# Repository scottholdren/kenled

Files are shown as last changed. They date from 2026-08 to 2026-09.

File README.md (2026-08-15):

# KenLED

An art installation: a wall of **89 glass bricks**, each lit by an addressable
RGB LED, playing pixel animations designed in a browser and delivered to the
wall over the air.

Design an animation on the web, hit **Publish**, and within seconds every
device subscribed to the wall — the installation itself and a pocket-sized
monitor — is playing it.

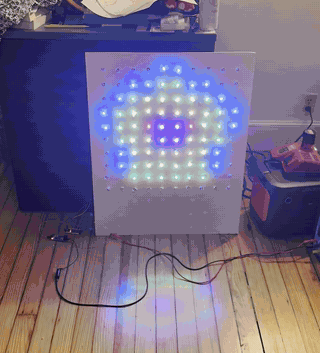
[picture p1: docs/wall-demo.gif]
The test rig playing the self-playing snake


*The 10×10 test rig: 100 WS2811 bullet pixels in foam board, driven by the
production firmware, playing a generated self-playing snake game published
over Wi-Fi seconds earlier. The glass-brick wall replaces the foam board;
everything else ships as-is.*

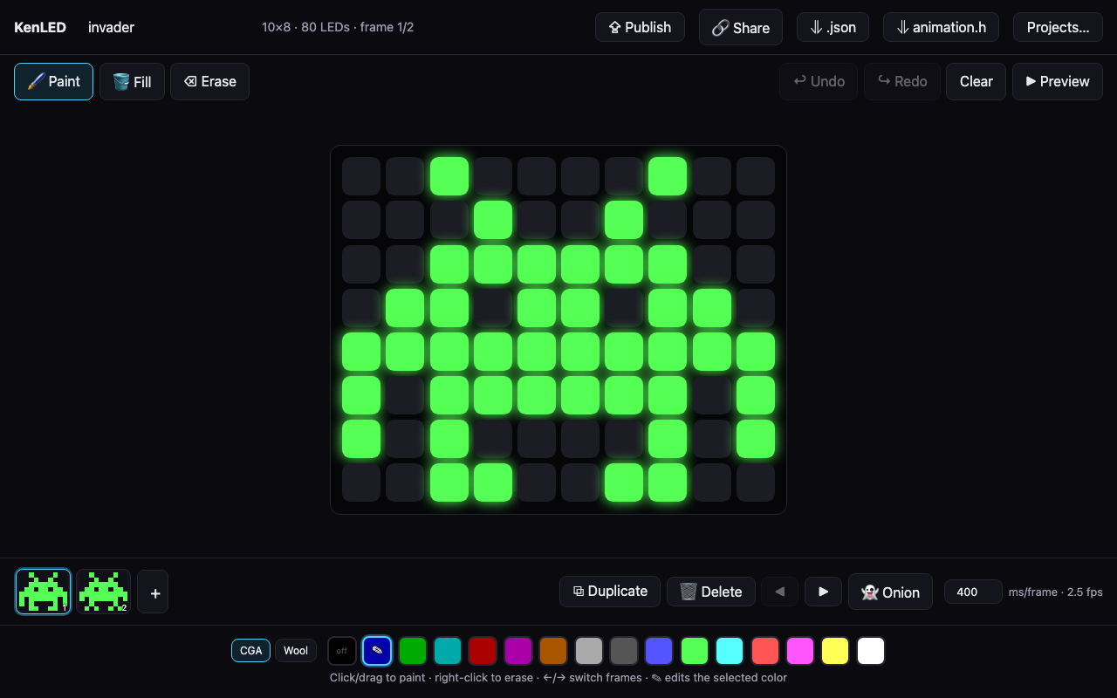
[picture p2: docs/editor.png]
The KenLED designer


## How it works

```
Designer's browser                 GitHub                       The wall
┌──────────────────┐  commit   ┌───────────────┐  poll ~60s  ┌──────────────────┐
│  KenLED designer │──────────▶│ wall branch:  │◀────────────│ ESP32-S3 +       │
│  (GitHub Pages)  │  via API  │ current.json  │             │ 89 WS2811 pixels │
│  [⇪ Publish]     │           └───────────────┘◀──────┐     └──────────────────┘
└──────────────────┘                                   │     ┌──────────────────┐
                                                       └─────│ LilyGo T-Dongle  │
                                                             │ (pocket mirror)  │
                                                             └──────────────────┘
```

- **The designer** is a static React app on GitHub Pages. Publishing commits
  the animation as `current.json` to this repo's `wall` branch through the
  GitHub API (a fine-grained token, held only in the designer's browser).
- **Devices** poll the branch-ref API (uncached; conditional 304s are free)
  and fetch content by immutable commit sha — updates land on the next poll,
  never stale-cached.
- **Playback never depends on the network.** Devices boot from a flash cache,
  fall back to a compiled-in animation, and just keep playing if Wi-Fi dies.
  Every published animation is also permanently recoverable from git history.

## The designer

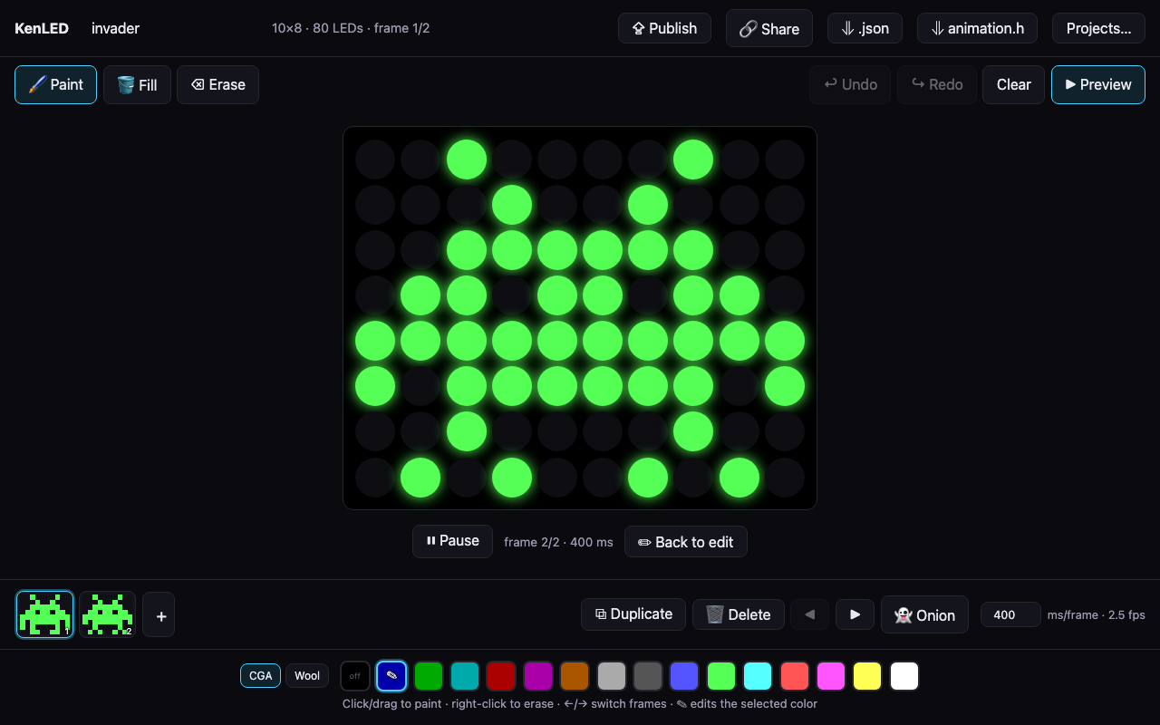
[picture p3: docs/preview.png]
Preview mode


- Configurable grid (default 10×8 — the brick wall), 16-color palette with
  **CGA** and **Minecraft wool** presets, every swatch editable
- Paint / fill / erase, drag-painting, click-to-toggle, undo/redo
- Frames: add, duplicate, delete, reorder, onion-skin ghosting (wraps around
  for seamless loops), adjustable frame rate
- Preview mode: glowing-dot simulation of the physical wall
- Autosave to the browser, multiple named projects
- **Share links** — the entire design compressed into a URL; a link is a
  backup, a save file, and a way to send designs around, no server involved
- Export as `.json` or as an `animation.h` C header for offline firmware
- **⇪ Publish** — one click to put it on the wall

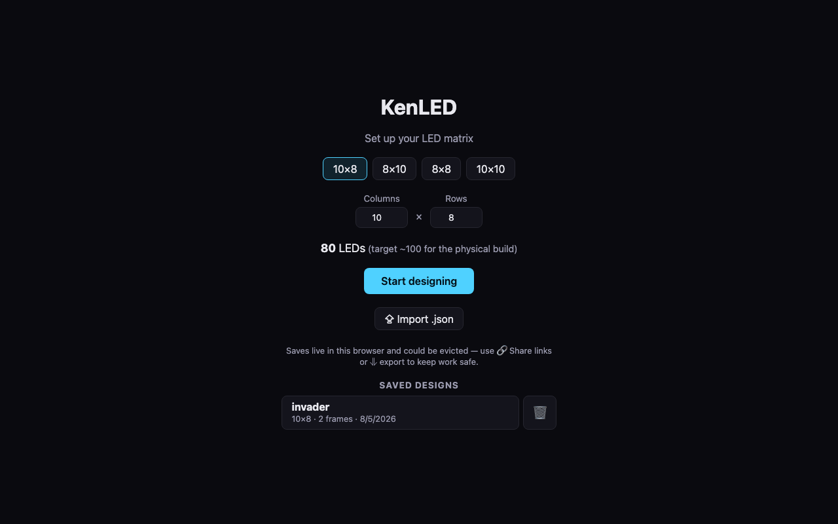
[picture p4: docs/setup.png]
Setup screen


## Firmware (`firmware/`)

One sketch: `kenled-wall` (ESP32-S3-DevKitC-1) — drives the WS2811 chain via
FastLED and pulls published animations over Wi-Fi. Compile-time update modes:
**poll** (live updates, dev), **boot-fetch** (pull once at power-on, then
radio off — the production mode: power-cycle the wall to update it), and
**offline** (no Wi-Fi compiled in at all). Offline-first in every mode: boots
from its flash cache, falls back to a compiled-in animation, and keeps
playing through any network failure. See `firmware/README.md` for build
flags, board settings, and wiring.

## Hardware

- 89× WS2811 12 V bullet pixels (one per glass brick, ~20 cm spacing)
- ESP32-S3-DevKitC-1 controller
- 12 V 10 A PSU (pixels) + 12 V→5 V buck (controller) — one wall plug
- Full BOM, wiring notes, and build order in [PLAN.md](PLAN.md)

### Test rig status (verified)

The complete production stack runs on a bench rig today: two 50-pixel WS2811
strings (10 cm spacing) mounted through foam board as a 10×10 grid, bench
supply at 12 V, data driven directly from the S3's GPIO 4 at 3.3 V logic —
no level shifter needed so far. Verified end to end on this rig:

- Color order (RGB channel probe), pixel-walk sweep of all 100 positions,
  serpentine + `FLIP_Y` mapping for a chain wired bottom-row-first
- Publish → pixels latency under 10 s (bench builds poll every 10 s; GitHub's
  conditional-request rules make this effectively free)
- Generated animations: a self-playing pong, a waving flag, a beating heart,
  a radiating rainbow star, a self-playing snake — animations are plain JSON,
  so anything scriptable is publishable
- Offline-first behavior under real failures: oversized payloads and network
  loss leave the wall playing the last good animation

Remaining for the installation: mount the pixels behind the glass bricks
(drill vs. back-mount pending a glow test), switch the firmware to boot-fetch
mode, and enable PSRAM in the build to lift the animation size ceiling.

## Development

```sh
npm install
npm run dev            # designer app at localhost:5173
npm run build          # production build (deployed by GitHub Actions on push)

# firmware (see firmware/README.md for FQBNs and flags)
arduino-cli compile --fqbn esp32:esp32:esp32s3:CDCOnBoot=cdc,FlashSize=16M,PartitionScheme=huge_app firmware/kenled-wall
```

Animations are plain JSON — grid size, a 16-color palette, frames as arrays
of palette indices — the same format in the app, the share links, the publish
pipeline, and (transposed to C) the compiled-in fallback.

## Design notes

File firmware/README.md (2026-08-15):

# KenLED Firmware

One firmware: **`kenled-wall/`** — the ESP32-S3-DevKitC-1 controller that
drives the WS2811 bullet-pixel chain and pulls the published wall animation
from GitHub. Playback never depends on the network: boot order is LittleFS
cache, then the compiled-in `animation.h` fallback.

(A LilyGo T-Dongle-C5 "pocket mirror" firmware previously lived here; it was
removed when the project settled on the S3. It's recoverable from git history
if ever wanted — along with its hard-won ST7735/APA102 quirk handling.)

## Build

- Board: **ESP32S3 Dev Module**, FQBN options
  `CDCOnBoot=cdc,FlashSize=16M,PartitionScheme=huge_app,PSRAM=opi`
  (**PSRAM=opi is required** — without it, large animations fail to parse).
- Libraries: **FastLED**, **ArduinoJson**.
- Wi-Fi credentials: copy `kenled-wall/wifi_secrets.h.example` to
  `wifi_secrets.h` (gitignored — the repo is public). Optionally add a
  zero-permission GitHub PAT as `GH_TOKEN` to raise the poll rate limit from
  60/hr (shared per IP) to 5000/hr.

```sh
arduino-cli compile --fqbn "esp32:esp32:esp32s3:CDCOnBoot=cdc,FlashSize=16M,PartitionScheme=huge_app,PSRAM=opi" \
  --build-property "compiler.cpp.extra_flags=-DBENCH_ONBOARD=0 -DUPDATE_MODE=0 -DPOLL_INTERVAL_MS=10000UL -DFLIP_Y=1" \
  firmware/kenled-wall
```

## Compile-time configuration

| Flag | Values | Meaning |
|---|---|---|
| `BENCH_ONBOARD` | `1` (default) / `0` | 1 = drive the DevKitC-1's onboard pixel (GPIO 48) for bench tests; 0 = the real WS2811/RGB chain on GPIO 4 |
| `UPDATE_MODE` | `0` poll / `1` boot-fetch / `2` offline | 0 = check GitHub every `POLL_INTERVAL_MS` (dev). **1 = production: fetch once at boot, then Wi-Fi off — power-cycle the wall to update it.** 2 = no Wi-Fi compiled in at all |
| `POLL_INTERVAL_MS` | ms | Poll cadence in mode 0 (default 60000; bench uses 10000) |
| `NUM_LEDS` | int | Physical chain length (default 100) |
| `FLIP_Y` | `0` / `1` | 1 if the chain's first row is the BOTTOM of the grid |
| `SERPENTINE` | in-file | Rows zigzag (default true) |
| `BRIGHTNESS`, `MAX_MILLIAMPS` | in-file | Global brightness cap and FastLED power limiter |

## Wiring

- Pixel 12 V and GND come **directly from the 12 V PSU**, never from the board.
- Board powers from USB or a 12V→5V buck; all grounds common.
- Data: GPIO 4 → (74AHCT125 level shifter if needed) → 330 Ω → first pixel DIN.
- Chain starts top-left... or bottom-left with `FLIP_Y=1`; rows serpentine.

## Changing the animation

Publish from the designer app (⇪ Publish). In poll mode the wall updates
within the poll interval; in boot-fetch mode, power-cycle the wall.

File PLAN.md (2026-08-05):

# KenLED — Addressable LED Matrix Art Installation

An art installation of ~100 addressable RGB LEDs arranged in a configurable grid
(8×8, 8×10, 8×9, etc.), driven by a microcontroller, with animations authored in a
web app published on GitHub Pages.

Two deliverables:

1. **Designer app** (this repo, published via GitHub Pages) — configure the grid,
   pick a 16-color palette, paint frames, preview the animation, export/publish it.
2. **Player firmware + hardware** — a microcontroller wired to the physical LED
   matrix that plays the published animation in meatspace.

---

## Part 1 — The Designer Web App

### Tech stack

- **Vite + React + TypeScript.** Pure static site — no backend, no accounts.
  GitHub Pages can host it directly.
- **Deploy:** GitHub Actions workflow builds on push to `main` and deploys to
  GitHub Pages (`actions/deploy-pages`). URL: `https://<user>.github.io/kenled/`.
- **Persistence:** `localStorage` autosave, plus explicit JSON file export/import
  so designs can be shared and versioned.

### Features (build in this order)

**Milestone 1 — Grid setup & single-frame painting**
- New-project screen: choose columns × rows (e.g. 8×8 … 8×13; free-form within
  a sane cap like 32×32, with a live LED-count readout since the physical build
  is ~100 LEDs).
- 16-color palette, pre-seeded with a good default set + black/off. Each swatch
  is editable via a color picker (palette is per-project, saved with the design).
- Paint tools: click to set a cell, click-drag to paint, right-click (or
  eraser tool) to clear, fill tool, clear-frame button.

**Milestone 2 — Frames & animation**
- Frame strip along the bottom: add, duplicate, delete, reorder frames;
  thumbnails of each frame.
- Onion-skin toggle (ghost of previous frame) — cheap to build, huge for animators.
- Frame duration: global FPS control (and optionally per-frame duration later).

**Milestone 3 — Preview & persistence**
- Preview mode: plays all frames in a loop at the chosen speed, rendered as
  glowing "LED" dots on black to approximate the real thing.
- Autosave to localStorage; project manager (multiple named designs).
- Export / import `.json` design files.
- Loss-prevention: `navigator.storage.persist()` to resist browser eviction,
  plus **share links** — the whole design deflate-compressed into the URL
  fragment. A link is a device-independent save/backup and the way animators
  send designs around; opening one imports it as a new local project.

**Milestone 4 — Hardware export**
- **Export as Arduino header (`animation.h`)** — palette + frame data as C
  arrays. The designer exports the header, drops it into the firmware sketch,
  and flashes once. (Scope decision: this is a flash-once, one-show
  installation — no Wi-Fi update loop needed.)

### Animation data format

One JSON document, shared by the app, the export, and the firmware:

```json
{
  "version": 1,
  "name": "my-animation",
  "cols": 8,
  "rows": 10,
  "frameDurationMs": 125,
  "palette": ["#000000", "#ff0000", "... 16 hex colors total"],
  "frames": [
    [0, 1, 3, 0, "... cols*rows palette indices, row-major, top-left origin"]
  ]
}
```

Palette-indexed frames keep files tiny (100 LEDs × 4 bits × N frames) and make
the 16-color constraint structural, not just a UI convention.

---

## Part 2 — Hardware Shopping List

Target: **89 glass bricks, one LED per brick** (~20 cm centers), indoor
installation. Grid modeled as 8×10 or 8×11 in the app.

Concrete order (2026-08-05): 2× ALITOVE WS2811 12V 50ct 8in-spacing bullet
strings (amzn B0BF4WBF41), ALITOVE 12V 10A PSU (B0FW512YH9), 12V→5V 5A buck,
SN74AHCT125N, barrel-jack screw-terminal adapter. ~$85 total.

| Item | Spec | Est. cost |
|---|---|---|
| LEDs | **WS2811 12 V 12 mm bullet pixels, 2× 50-count strings, 20 cm wire spacing** (spacing must reach brick centers — don't buy the default 10 cm). 89 used + 11 spares. Press-fit a 12 mm drilled hole, or silicone to the back of each block. | $40–50 |
| Controller | ✔ **On hand: ESP32-S3-DevKitC-1-N16R8 (×3, AITRIP)** — Wi-Fi + BLE, 16 MB flash, 8 MB PSRAM | $0 |
| Power supply | **12 V, 10 A** (89 px × ~60 mA ≈ 5.4 A worst case; headroom is cheap) | $20–30 |
| Buck converter | 12 V → 5 V, ≥1 A, to power the ESP32 from the same PSU | $3–5 |
| Level shifter | 74AHCT125 — shifts the ESP32's 3.3 V data signal to a solid 5 V | $2 |
| Capacitor | 1000 µF electrolytic (≥16 V) across the power rails at the chain start | $1 |
| Resistor | 300–500 Ω on the data line at the first pixel (many pixel strings have one built in) | $1 |
| Wiring & connectors | 18 AWG for power runs, JST-SM 3-pin pigtails, screw terminal for the PSU | $10 |

Wiring notes for the build:
- ~18–20 m total chain length. 12 V keeps droop manageable — inject power at
  the chain start and once mid-chain.
- **Never** power the pixels through the microcontroller's USB — pixels get PSU
  power directly; controller and pixels share ground.
- Route the chain through the bricks in a **serpentine** (zigzag) matching the
  grid; the firmware maps (x, y) → chain index so the app never has to care.
- Mounting decision (drill 12 mm holes vs. back-mount with silicone): test one
  brick with a back-mounted pixel in the dark before committing to 89 holes.
- If the physical brick layout is not a clean rectangle, add a skip-mask to the
  export + firmware (planned only if needed).

---

## Part 3 — Player Firmware

Target hardware (on hand): **ESP32-S3-DevKitC-1-N16R8** ×3.

- Arduino IDE: install the `esp32` boards package (Espressif), select board
  **"ESP32S3 Dev Module"**. 16 MB flash / 8 MB (octal) PSRAM.
- 3.3 V logic — keep the 74AHCT125 level shifter on the pixel data line.
- Bullet pixels are **WS2811, usually RGB order** (vs. the strip's
  WS2812B/GRB): set `FastLED.addLeds<WS2811, DATA_PIN, RGB>` — confirm color
  order with the first lit pixel.
- Data pin: use a plain GPIO (e.g. GPIO 4). Avoid strapping pins (0, 3, 45, 46)
  and USB pins (19, 20).
- The DevKitC-1 has an **onboard WS2812 RGB LED on GPIO 48** — the firmware
  can be bench-tested against that single pixel before the matrix arrives.

- **Arduino IDE + FastLED** targeting the ESP32-S3.
- Scope: **flash once for the show.** The animation is compiled in from the
  exported `animation.h`; the sketch loops it forever. No Wi-Fi, no runtime
  updates. To change the animation: re-export the header, re-flash.
- Responsibilities:
  - Serpentine coordinate mapping `(x, y) → led index`, matching the physical wiring.
  - Global brightness cap and FastLED power limiting (`setMaxPowerInVoltsAndMilliamps`)
    as a safety net for the PSU.
  - Loop the compiled-in animation at its frame rate, all night.

---

## Status (2026-08-05)

Everything software is DONE and hardware-verified except the physical string:

- Designer app live (gate passphrase, CGA/Wool palettes, toggle-paint, frames,
  onion skin, preview, share links, autosave, JSON/animation.h export,
  **Publish to wall**).
- Publish pipeline: app -> `current.json` on the `wall` branch -> devices
  poll the branch-ref API and fetch by commit sha. Sub-60s latency verified.
- `firmware/kenled-mirror` (T-Dongle-C5): screen mirror + updates. Verified.
- `firmware/kenled-wall` (ESP32-S3): production controller — FastLED + same
  update machinery, three compile-time update modes. Verified on the onboard
  pixel (BENCH_ONBOARD=1); production config compiles (WS2811/RGB, GPIO 4).
- Hardware ordered: 2× 50ct WS2811 12V bullet strings (20cm), 12V 10A PSU,
  12V->5V buck, 74AHCT125.

Remaining: physical assembly when the box arrives — first-light color-order
check, one-brick glow test (drill vs back-mount), then install.

## Part 4 — Build Order

1. **Repo & deploy skeleton** — Vite + React + TS scaffold, GitHub repo,
   Pages workflow deploying a hello-world page. Proves the publishing pipeline first.
2. **Milestones 1–3 of the app** — grid setup → painting → frames → preview →
   save/load. The designer can fully author animations before any hardware exists.
3. **Order hardware** (can overlap with step 2 — shipping takes time).
4. **Milestone 4 export + firmware** — light up the real matrix from an
   exported header file.
5. **Physical install** — mounting, diffusion, power routing, final placement.

## Open decisions

- **Panels vs. strip-built matrix:** pre-built 8×8 panels are plug-and-play but
  fix the grid pitch; hand-built from strips lets you match the art's dimensions.
- **Exact grid dimensions** — decide before ordering (drives panel vs. strip choice).
- ~~ESP32 vs. plain Arduino~~ — **resolved**: ESP32-S3-DevKitC-1-N16R8 boards on hand.
- ~~How "publish" works~~ — **resolved**: flash-once for the show; the animation
  ships compiled into the firmware via `animation.h`. No runtime updates.

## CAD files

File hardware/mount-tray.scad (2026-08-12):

// KenLED controller mounting tray — ESP32-S3-DevKitC-1 + DROK USB buck.
// Prints flat, no supports. Screws or VHB-tapes into the junction box.
// v3: both bays centered; corner screw holes have clear webbing all around.

// ---- parameters (mm) ----
s3_len = 62;      // DevKitC-1 board length (measured)
s3_wid = 28;      // board width (measured)
pcb_t = 1.8;      // rail groove height (1.6mm PCB + slip)
rail_lip = 0.4;   // lip overhang — tiny, clears the header pins

drok_len = 63;    // DROK buck length (measured)
drok_wid = 27;    // DROK width (measured)
drok_wall = 8;    // cradle side-wall height

base_t = 3;       // baseplate thickness
gap = 12;         // spacing between the two bays
edge = 18;        // clear border around the bays (screw holes live here)
hole_inset = 7;   // screw hole distance from tray corners

// ---- derived layout (everything centered) ----
tray_len = max(s3_len, drok_len) + 2 * edge;
content_h = (s3_wid + 8) + gap + (drok_wid + 4); // s3 bay + gap + drok bay
tray_wid = content_h + 2 * edge;

s3_x = (tray_len - s3_len) / 2;
s3_y = edge + 4;                       // s3 board's lower edge
drok_x = (tray_len - drok_len) / 2;
drok_y = edge + 8 + s3_wid + gap + 2;  // drok module's lower edge

// ---- baseplate with corner screw holes + drok zip-tie slots ----
difference() {
  cube([tray_len, tray_wid, base_t]);
  for (x = [hole_inset, tray_len - hole_inset], y = [hole_inset, tray_wid - hole_inset])
    translate([x, y, -1]) cylinder(h = base_t + 2, d = 3.5, $fn = 24); // M3
  // zip-tie slot pairs flanking the DROK bay
  for (x = [drok_x + drok_len * 0.25, drok_x + drok_len * 0.75 - 8])
    for (y = [drok_y - 6, drok_y + drok_wid + 3])
      translate([x, y, -1]) cube([8, 3, base_t + 2]);
}

// ---- bay 1: S3 edge rails (ends open — USB reachable; slide in from an end) ----
// outer rail, lip faces +y (toward the board)
translate([s3_x, s3_y - 4, base_t]) difference() {
  cube([s3_len, 4, pcb_t + 2.4]);
  translate([-1, 4 - rail_lip, 1.2]) cube([s3_len + 2, rail_lip + 1, pcb_t]);
}
// inner rail, lip faces -y
translate([s3_x, s3_y + s3_wid, base_t]) difference() {
  cube([s3_len, 4, pcb_t + 2.4]);
  translate([-1, -1, 1.2]) cube([s3_len + 2, rail_lip + 1, pcb_t]);
}
// end stop (one end only, so the board can still slide in; the box wall
// or lid backs up the open end)
translate([s3_x + s3_len, s3_y - 4, base_t]) cube([2, s3_wid + 8, 4]);

// ---- bay 2: DROK cradle — side walls only, BOTH ENDS OPEN for terminals/USB ----
for (y = [drok_y - 2, drok_y + drok_wid])
  translate([drok_x, y, base_t]) cube([drok_len, 2, drok_wall]);

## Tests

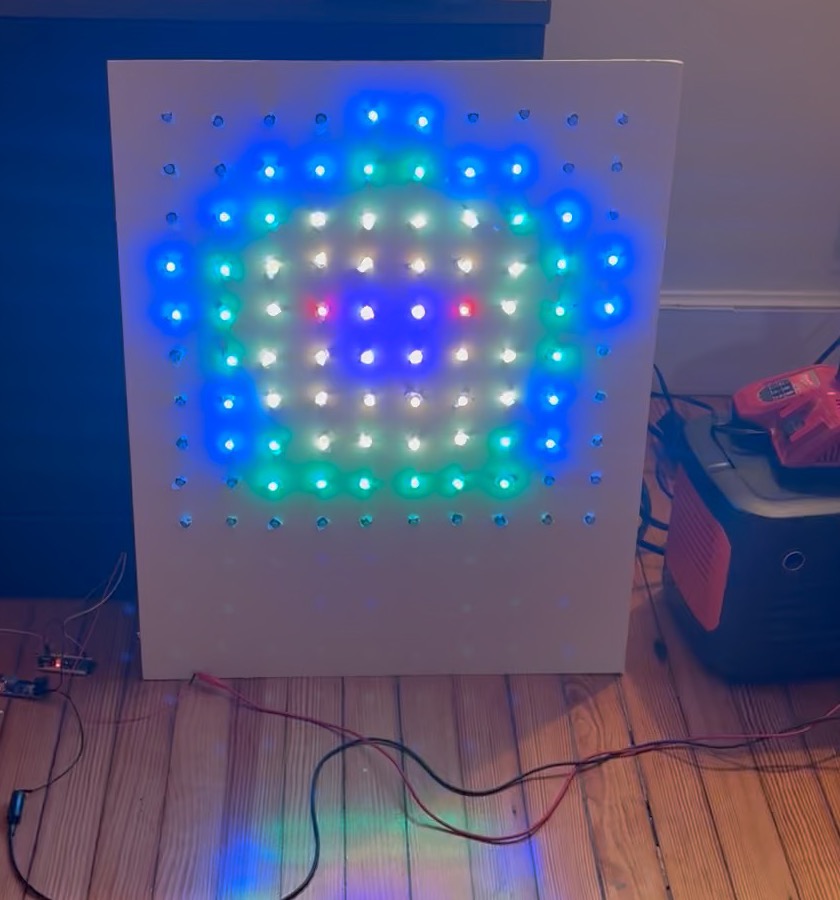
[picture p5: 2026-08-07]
docs/test-rig.jpg

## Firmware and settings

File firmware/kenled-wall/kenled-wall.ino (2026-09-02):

// KenLED wall — production controller firmware (ESP32-S3-DevKitC-1).
//
// Drives the WS2811 bullet-pixel chain and (unless offline) pulls the
// published wall animation from GitHub. Same update machinery as the
// kenled-mirror dongle: LittleFS cache -> compiled-in fallback; network
// only ever ADDS updates, playback never depends on it.
//
// Board: "ESP32S3 Dev Module". Libraries: FastLED, ArduinoJson.
// Wi-Fi credentials: copy wifi_secrets.h.example to wifi_secrets.h.
//
// BENCH TEST (no string yet): BENCH_ONBOARD 1 drives the DevKitC-1's onboard
// WS2812 (GPIO 48) — it plays the animation's top-left cell. Set to 0 for
// the real chain on DATA_PIN through the level shifter.

#include <FastLED.h>
#include <WiFi.h>
#include <WiFiMulti.h>
#include <WiFiClientSecure.h>
#include <HTTPClient.h>
#include <ArduinoJson.h>
#include <LittleFS.h>
#include "wifi_secrets.h"
#include "animation.h" // compiled-in fallback

#ifndef BENCH_ONBOARD
#define BENCH_ONBOARD 1
#endif

#if BENCH_ONBOARD
#define DATA_PIN 48 // DevKitC-1 onboard pixel (some revisions: 38)
#define LED_TYPE WS2812
#define COLOR_ORDER GRB
#else
#define DATA_PIN 4 // through the 74AHCT125 level shifter
#define LED_TYPE WS2811
#define COLOR_ORDER RGB
#endif

#ifndef NUM_LEDS
#define NUM_LEDS 100 // physical chain length (89 bricks + spares)
#endif
#define SERPENTINE true // rows zigzag; flip if wired parallel
#ifndef FLIP_Y
#define FLIP_Y 0 // 1 if the chain's first row is the BOTTOM of the grid
#endif
#define BRIGHTNESS 48
#define MAX_MILLIAMPS 8000 // FastLED's estimate assumes 5V; still a sane cap

#define REF_URL "https://api.github.com/repos/scottholdren/kenled/git/ref/heads/wall"
#define RAW_BASE "https://raw.githubusercontent.com/scottholdren/kenled/"
#ifndef POLL_INTERVAL_MS
#define POLL_INTERVAL_MS 60000UL
#endif
#define CACHE_PATH "/current.json"
#define INCOMING_PATH "/incoming.json"

// ---- Update mode (compile-time), same semantics as kenled-mirror ----
//   0 MODE_POLL / 1 MODE_BOOT_FETCH (production: power-cycle to update) / 2 MODE_OFFLINE
#define MODE_POLL 0
#define MODE_BOOT_FETCH 1
#define MODE_OFFLINE 2
#ifndef UPDATE_MODE
#define UPDATE_MODE MODE_POLL
#endif

#define MAX_DIM 32
#define MAX_ANIM_BYTES 65536

struct Anim {
  uint16_t cols, rows, frameCount, frameMs;
  uint32_t palette[16];
  uint8_t* cells;
};

CRGB leds[NUM_LEDS];
#if UPDATE_MODE != MODE_OFFLINE
WiFiMulti wifiMulti; // connects to whichever configured network is present
#endif
Anim* current = nullptr;
Anim* pending = nullptr;
SemaphoreHandle_t pendingMux;
volatile uint32_t lastFetchOkAt = 0;

void freeAnim(Anim* a) {
  if (a == nullptr) return;
  free(a->cells);
  free(a);
}

// Designer grid is row-major, origin top-left. Maps grid position -> chain index.
uint16_t ledIndex(uint8_t x, uint8_t y, uint16_t cols, uint16_t rows) {
  if (FLIP_Y) y = rows - 1 - y;
  if (SERPENTINE && (y & 1)) return (uint16_t)y * cols + (cols - 1 - x);
  return (uint16_t)y * cols + x;
}

// ---- Animation parsing (same rules as the app's importer) ----

Anim* animFromDoc(JsonDocument& doc) {
  int cols = doc["cols"] | 0;
  int rows = doc["rows"] | 0;
  JsonArray pal = doc["palette"];
  JsonArray frames = doc["frames"];
  if (cols < 1 || cols > MAX_DIM || rows < 1 || rows > MAX_DIM) return nullptr;
  if (pal.size() != 16 || frames.size() < 1) return nullptr;
  size_t cellCount = (size_t)cols * rows;
  size_t frameCount = frames.size();
  if (cellCount * frameCount > MAX_ANIM_BYTES) return nullptr;

  Anim* a = (Anim*)malloc(sizeof(Anim));
  if (a == nullptr) return nullptr;
  a->cells = (uint8_t*)malloc(cellCount * frameCount);
  if (a->cells == nullptr) {
    free(a);
    return nullptr;
  }
  a->cols = cols;
  a->rows = rows;
  a->frameCount = frameCount;
  int ms = doc["frameDurationMs"] | 125;
  a->frameMs = constrain(ms, 30, 2000);
  for (int i = 0; i < 16; i++) {
    const char* hex = pal[i] | "#000000";
    a->palette[i] = strtoul(hex[0] == '#' ? hex + 1 : hex, nullptr, 16);
  }
  size_t w = 0;
  for (JsonArray f : frames) {
    if (f.size() != cellCount) {
      freeAnim(a);
      return nullptr;
    }
    for (int v : f) a->cells[w++] = (v >= 0 && v < 16) ? v : 0;
  }
  return a;
}

Anim* parseAnimFile(const char* path) {
  File f = LittleFS.open(path, "r");
  if (!f) return nullptr;
  JsonDocument doc;
  DeserializationError err = deserializeJson(doc, f);
  f.close();
  if (err != DeserializationError::Ok) {
    Serial.printf("[parse] %s: %s\n", path, err.c_str());
    return nullptr;
  }
  return animFromDoc(doc);
}

#if UPDATE_MODE != MODE_OFFLINE
// Streams to flash and frees TLS BEFORE parsing (heap headroom).
void fetchAnimation(const String& sha) {
  bool downloaded = false;
  {
    WiFiClientSecure client;
    client.setInsecure();
    HTTPClient http;
    http.begin(client, RAW_BASE + sha + "/current.json");
    int code = http.GET();
    if (code == 200) {
      File f = LittleFS.open(INCOMING_PATH, "w");
      if (f) {
        http.writeToStream(&f);
        f.close();
        downloaded = true;
      }
    } else {
      Serial.printf("[poll] raw fetch HTTP %d\n", code);
    }
    http.end();
  }
  if (!downloaded) return;
  Anim* a = parseAnimFile(INCOMING_PATH);
  if (a != nullptr) {
    LittleFS.remove(CACHE_PATH);
    LittleFS.rename(INCOMING_PATH, CACHE_PATH);
    xSemaphoreTake(pendingMux, portMAX_DELAY);
    freeAnim(pending);
    pending = a;
    xSemaphoreGive(pendingMux);
    Serial.printf("[poll] updated to %s: %ux%u %u frames\n", sha.substring(0, 7).c_str(), a->cols,
                  a->rows, a->frameCount);
  } else {
    Serial.println("[poll] fetched but invalid animation json");
  }
}

void pollTask(void*) {
  String refEtag = "";
  String lastSha = "";
  for (;;) {
    if (WiFi.status() != WL_CONNECTED) {
      wifiMulti.run(10000); // tries all configured networks, best signal first
    }
    if (WiFi.status() == WL_CONNECTED) {
      WiFiClientSecure client;
      client.setInsecure();
      HTTPClient http;
      http.begin(client, REF_URL);
      http.setUserAgent("kenled-wall");
#ifdef GH_TOKEN
      http.addHeader("Authorization", "Bearer " GH_TOKEN);
#endif
      if (refEtag.length() > 0) http.addHeader("If-None-Match", refEtag);
      const char* keys[] = {"ETag"};
      http.collectHeaders(keys, 1);
      int code = http.GET();
      if (code == 304) {
        lastFetchOkAt = millis();
        Serial.println("[poll] ref unchanged");
        http.end();
      } else if (code == 200) {
        String etag = http.header("ETag");
        JsonDocument doc;
        DeserializationError err = deserializeJson(doc, http.getString());
        http.end();
        const char* sha = doc["object"]["sha"] | "";
        if (err == DeserializationError::Ok && strlen(sha) == 40) {
          if (lastSha != sha) {
            fetchAnimation(String(sha));
            lastSha = sha;
          }
          refEtag = etag;
          lastFetchOkAt = millis();
        } else {
          Serial.println("[poll] bad ref response");
        }
      } else {
        Serial.printf("[poll] ref HTTP %d\n", code);
        http.end();
      }
    }
#if UPDATE_MODE == MODE_BOOT_FETCH
    if (lastFetchOkAt != 0) {
      WiFi.disconnect(true);
      WiFi.mode(WIFI_OFF);
      Serial.println("[poll] boot fetch complete, wifi off");
      vTaskDelete(nullptr);
    }
    vTaskDelay(pdMS_TO_TICKS(15000));
#else
    vTaskDelay(pdMS_TO_TICKS(POLL_INTERVAL_MS));
#endif
  }
}
#endif // UPDATE_MODE != MODE_OFFLINE

// ---- Boot ----

Anim* builtinAnim() {
  Anim* a = (Anim*)malloc(sizeof(Anim));
  size_t total = (size_t)ANIM_NUM_LEDS * ANIM_FRAME_COUNT;
  a->cells = (uint8_t*)malloc(total);
  memcpy(a->cells, ANIM_FRAMES, total);
  a->cols = ANIM_COLS;
  a->rows = ANIM_ROWS;
  a->frameCount = ANIM_FRAME_COUNT;
  a->frameMs = ANIM_FRAME_MS;
  memcpy(a->palette, ANIM_PALETTE, sizeof(a->palette));
  return a;
}

void setup() {
  Serial.begin(115200);

  FastLED.addLeds<LED_TYPE, DATA_PIN, COLOR_ORDER>(leds, NUM_LEDS);
  FastLED.setBrightness(BRIGHTNESS);
  FastLED.setMaxPowerInVoltsAndMilliamps(5, MAX_MILLIAMPS);
  FastLED.clear(true);

  pendingMux = xSemaphoreCreateMutex();

  Anim* boot = nullptr;
  if (LittleFS.begin(true)) {
    boot = parseAnimFile(CACHE_PATH);
    if (boot != nullptr) Serial.println("[boot] playing cached animation");
  }
  if (boot == nullptr) {
    boot = builtinAnim();
    Serial.println("[boot] playing compiled-in animation");
  }
  current = boot;

#if UPDATE_MODE != MODE_OFFLINE
  WiFi.mode(WIFI_STA);
  wifiMulti.addAP(WIFI_SSID, WIFI_PASS);
#ifdef WIFI_SSID2
  wifiMulti.addAP(WIFI_SSID2, WIFI_PASS2);
#endif
  xTaskCreate(pollTask, "poll", 8192, nullptr, 1, nullptr);
#endif
}

void showFrame(uint16_t fi) {
  const uint8_t* frame = current->cells + (size_t)fi * current->cols * current->rows;
  FastLED.clear();
  for (uint8_t y = 0; y < current->rows; y++) {
    for (uint8_t x = 0; x < current->cols; x++) {
      uint16_t idx = ledIndex(x, y, current->cols, current->rows);
      if (idx < NUM_LEDS) leds[idx] = CRGB(current->palette[frame[y * current->cols + x]]);
    }
  }
  FastLED.show();
}

void loop() {
  static uint16_t f = 0;
  static uint32_t nextAt = 0;

  if (pending != nullptr) {
    xSemaphoreTake(pendingMux, portMAX_DELAY);
    Anim* a = pending;
    pending = nullptr;
    xSemaphoreGive(pendingMux);
    freeAnim(current);
    current = a;
    f = 0;
    nextAt = 0;
  }

  uint32_t now = millis();
  if (now < nextAt) return;
  nextAt = (now > nextAt + current->frameMs) ? now + current->frameMs : nextAt + current->frameMs;
  showFrame(f);
  f = (f + 1) % current->frameCount;
}

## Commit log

2026-08-05 Milestone 2: frame strip with add/duplicate/delete/reorder, onion skin, frame duration
2026-08-05 Plan: controller resolved — ESP32-S3-DevKitC-1-N16R8 boards on hand
2026-08-05 Milestone 4: animation.h export + flash-once ESP32-S3 firmware
    Scope simplified per show requirements: single animation compiled in,
    no Wi-Fi update loop.
2026-08-05 Plan: LEDs resolved — 12V WS2811 bullet pixels for 89-glass-brick wall
2026-08-05 Mirror: hardware SPI at 27MHz, swap BGR panel channels
2026-08-05 Mirror: panel needs neither inversion nor RB swap — both flags off
2026-08-05 Mirror: double-buffered rendering + drift-free frame pacing
2026-08-05 Mirror: drive status APA102 off via vendored Pololu lib, re-asserted per frame
2026-08-05 Mirror: APA102 shares the LCD SPI bus on this board rev — send off-frame after each blit
2026-08-05 Mirror: zero-filled APA102 end frame — 0xFF tail was itself a white frame on SK9822 clones
2026-08-05 Mirror: near-black pixels kill APA102 zero-run start frames — pixel can't hear the blit
2026-08-05 Publish-to-wall: commit current.json to wall branch via GitHub API
2026-08-05 Phase 2: Wi-Fi polling firmware — runtime animations, ETag polling, LittleFS cache
2026-08-05 Poller: track wall branch via GitHub ref API + immutable by-sha raw fetch
    Branch raw URLs sit behind an edge cache that ignores query strings and can
    lag pushes by many minutes; the ref API is uncached and conditional 304s are
    rate-limit-free, so updates now land on the next poll.
2026-08-05 Poller: stream download to flash, free TLS before parsing — fixes OOM on large animations
2026-08-05 kenled-wall: production S3 firmware — FastLED chain + same update machinery, bench mode on onboard pixel
2026-08-05 Plan: status update — full software stack verified on both boards
2026-08-07 kenled-wall: FLIP_Y mapping for chains wired bottom-row-first
    [kenled-wall.ino]
2026-08-12 hardware: printable mounting tray for S3 + DROK buck
    [mount-tray.scad]
2026-08-12 Mount tray: open both DROK ends — screw terminals and USB were walled in
    [mount-tray.scad]
2026-08-12 Mount tray: measured board dimensions
    [mount-tray.scad]
2026-08-12 Mount tray v3: centered bays, screw holes clear of all geometry
    [mount-tray.scad]
2026-08-12 Mount tray: widen clear border to 18mm
    [mount-tray.scad]
2026-08-15 Retire dongle mirror and vestigial offline sketch — S3 wall firmware only
    Both recoverable from git history, including the T-Dongle-C5 panel/APA102
    quirk handling.
2026-08-15 Describe: live progress (thinking timer + streaming byte counter), medium effort, fewer default frames, Enter saves key
2026-08-15 Fix: preview stops stealing keys from inputs; duration field allows free typing, clamps on commit; bias smaller generations
2026-09-02 Multi-network Wi-Fi via WiFiMulti — home + venue without reflashing
